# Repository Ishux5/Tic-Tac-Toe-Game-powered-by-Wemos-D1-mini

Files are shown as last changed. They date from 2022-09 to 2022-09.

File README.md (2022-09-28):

# Tic-Tac-Toe-Game-powered-by-Wemos-D1-mini

## Idea:

The Idea started when I was working on a birthday present for a friend. It was a 7 Segment Clock powered by an ESP32. The core part was to build something powered by a microcontroller by using a PCB and a Bettery Pack. I then setteled on building a Tic-Tac-Toe because I thought it was relatively simple. The code would be simple, the PCB-layout would be simple and it would be easy to manufacture a couple of them.

## Journey

After setteling on the idea I started working on the form. It shouldn't be to big and I wanted it to have a maximum size of 10 cm x 10 cm. After finishing the first 3D Model in Autodesk Fusion 360 I continued with creating the circuit which I never done before. I screen recorded my work and decided to create a little Video about how I made the PCB, Code and the casing. PCB and Code are older Versions and non functional!
Tic-Tac-Toe making of (https://youtu.be/2Q2LxaJ6QfE "Tic-Tac-Toe making of")
<br>
The first ordered sample worked but had a huge flaw as I connected the LEDs to the wrong Pins on the micro Controller. Pin 8 and 1 weren't functioning as internal Pullup pins. The second and current version is still flawed because of to small holes for the Power Switch. I have not reordered any PCBs with the right hole sizes.

## Finished Product

After all I am very Happy how it turned out. It is functioning as I wanted it, looks decend and the learning experience on the journey to the finished product was fun too. It has become more elaborate and costly than expected

## Parts

| Item # | Component | Quantity |
| :----- | :--- | :--- |
| 1 | [Cherry MX Blue switches, MX1A-E1NA][switchlink] | 9 |
| 2 | [AZDelivery Battery Shield for D1 Mini][shieldlink] | 1 |
| 3 | [AZDelivery D1 Mini NodeMcu ESP8266-12F][microcontrollerlink] | 1 |
| 4 | [LiPo 1200mAh 3,7V Batterie][lipolink] | 1 |
| 5 | [SK6812 MINI-E RGB][ledlink] | 11 |
| 6 | [SALECOM SS 13ASP][powerswtichlink] | 1 |
| 7 | [Short-Stroke switch 5mm][shortstrokelink] | 1 |
| 8 | [Micro USB to DIP breakout Board][usbbreakoutlink] | 1 |
| 9 | JST – Connecter Female 90° | 1 |
| 10 | [JST – Connector wire][jstwirelink] | 1 |
| 11 | 10k Ohm Resistor | 1 |
| 12 | 100k Ohm Resistor | 1 |
| 13 | [Micro USB Power Cable 20 cm][usbwirelink] | 1 |
| 14 | [M4 Threaded Inserts][insertslink] | 4 |
| 15 | M4 Cylindrical Screws | 4 |
| 16 | [Tic-Tac-Toe PCB][pcblink] | 1 |

[switchlink]: https://de.aliexpress.com/item/1005003772714638.html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
[shieldlink]: https://www.amazon.de/-/en/dp/B07XB75NTD/ref=twister_B07ZRK81LT?_encoding=UTF8&psc=1
[microcontrollerlink]: https://www.az-delivery.de/collections/alle-produkte/products/d1-mini
[lipolink]: https://www.ebay.de/itm/282581166241
[ledlink]: https://de.aliexpress.com/item/1005002865070175.html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
[powerswitchlink]: https://www.reichelt.de/schiebeschalter-1x-um-stehend-print-rm-4-7-ss-13asp-p112182.html?&nbc=1
[shortstrokelink]: https://www.reichelt.de/kurzhubtaster-6x6mm-hoehe-7-0mm-12v-vertikal-taster-9303-p44583.html?&nbc=1
[usbbreakoutlink]: https://www.amazon.de/gp/product/B07W13X3TD/ref=ppx_yo_dt_b_asin_title_o00_s00?ie=UTF8&psc=1
[jstwirelink]: https://www.reichelt.de/jst-stiftleiste-90-1x2-polig-ph-jst-ph2p-st90-p185056.html?&nbc=1
[usbwirelink]: https://www.reichelt.de/micro-usb-b-stecker-auf-freie-enden-sw-20-cm-usb-b-awg22-20-p292508.html?&nbc=1
[insertslink]: https://www.amazon.de/gp/product/B09CL4M6JB/ref=ppx_yo_dt_b_asin_title_o01_s02?ie=UTF8&psc=1
[pcblink]: https://www.pcbway.com/project/shareproject/Tic_Tac_Toe_5d14ccaf.html

## Assembly

1. Solder LEDs to the PCB (ground marked with while dot)
2. Solder Button 2 (opposite to D1 mini at LED2) to the PCB
3. Install the Software on the D1 mini
4. Solder D1 mini to the PCB
5. Solder the Power Switch, Resistors, JST – Connector and short-stroke switch to the PCB
6. Solder JST – Connector wire to the Battery shield
7. Solder Micro USB cable to the Micro USB breakout board
8. Insert the Button on the PCB through the larger hole in the 3D – Printed top part of the Casing
9. Insert rest of the Buttons in the Holes of the 3D – Printed top part of the Casing
10. Solder Buttons to the PCB
11. Connect the Battey and Micro USB Cable to the Battery Shield
12. Install M4 Threaded Inserts
13. Route Cables in the 3D – Printed bottom part of the Casing
14. Connect the JST – Male header with the JST – Female header on the PCB

## License

Shield: [][cc-by-nc-sa]

This work is licensed under a
[Creative Commons Attribution-NonCommercial-ShareAlike 4.0 International License][cc-by-nc-sa].

[][cc-by-nc-sa]

[cc-by-nc-sa]: http://creativecommons.org/licenses/by-nc-sa/4.0/
[cc-by-nc-sa-image]: https://licensebuttons.net/l/by-nc-sa/4.0/88x31.png
[cc-by-nc-sa-shield]: https://img.shields.io/badge/License-CC%20BY--NC--SA%204.0-lightgrey.svg

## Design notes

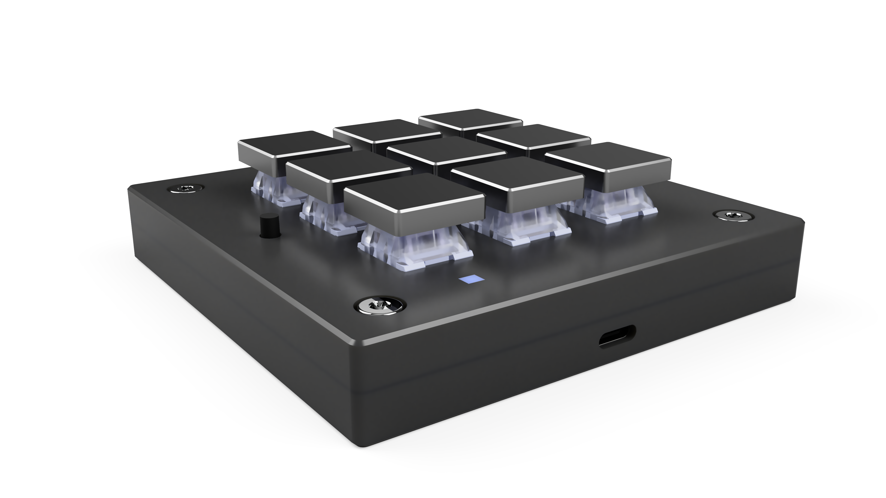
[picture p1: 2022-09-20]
Images/Konstruktion_2022-Sep-20_01-05-23AM-000_CustomizedView2792266026_png.png

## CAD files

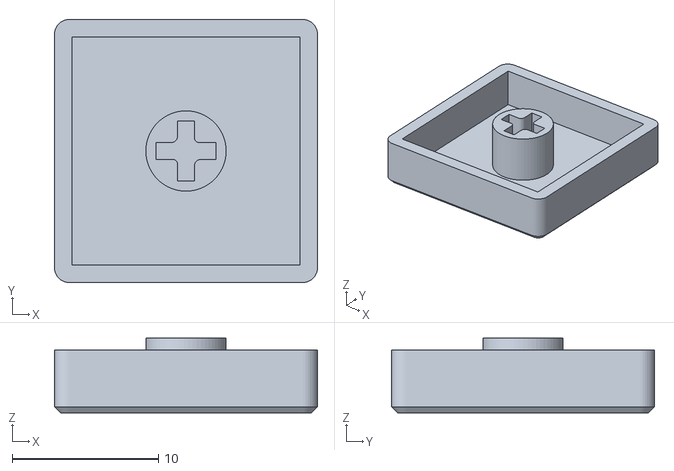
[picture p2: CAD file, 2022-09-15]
Pre1 Keycap.stl
18.0 x 18.0 x 5.10

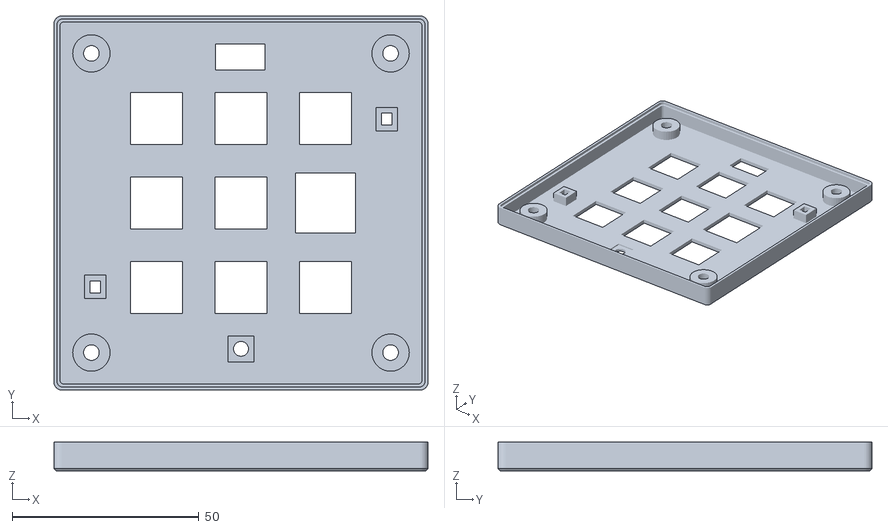
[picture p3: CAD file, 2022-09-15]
Pre2 Deckel.stl
100.0 x 100.0 x 7.70

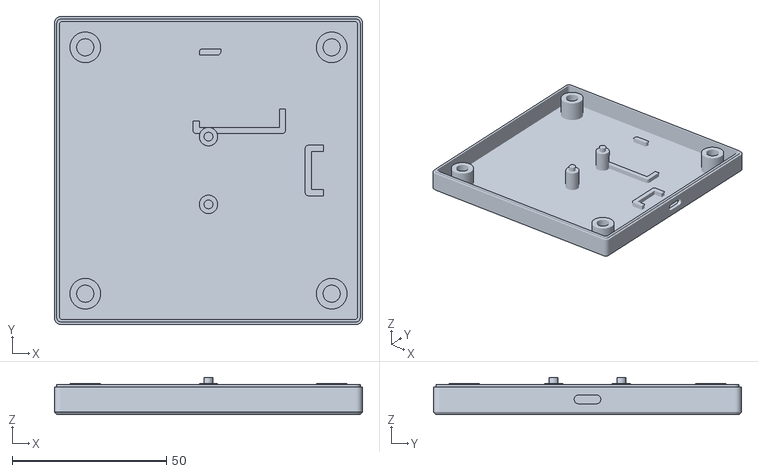
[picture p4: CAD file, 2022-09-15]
Pre2 Boden.stl
100.0 x 100.0 x 12.1

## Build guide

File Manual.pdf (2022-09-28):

# Arduino Based Tic-Tac-Toe

By Christian Rahn

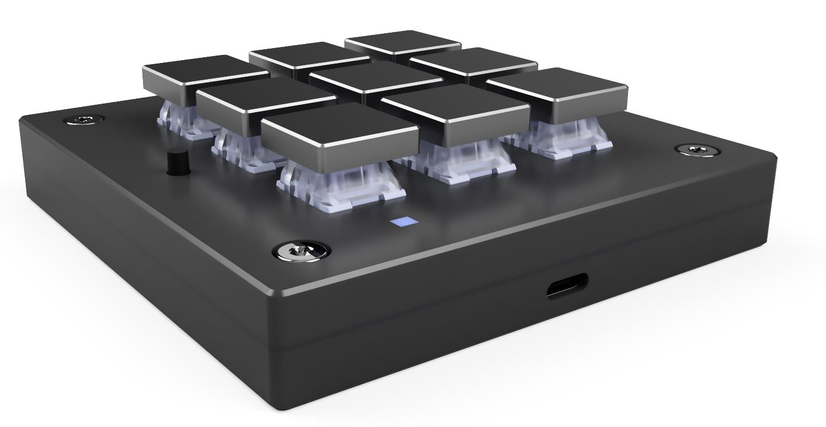
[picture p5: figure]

## Content

## License

This work is licensed under a Creative Commons Attribution-NonCommercial-ShareAlike 4.0 International License. (http://creativecommons.org/licenses/by-nc-sa/4.0/)

## Prolog

### Idea:

The Idea started when I was working on a birthday present for a friend. It was a 7 Segment Clock powered by an ESP32. The core part was to build something powered by a microcontroller by using a PCB and a Battery Pack. I then settled on building a Tic-Tac-Toe because I thought it was relatively simple. The code would be simple, the PCB-layout would be simple, and it would be easy to manufacture a couple of them.

### Journey:

After settling on the idea, I started working on the form. It shouldn't be too big, and I wanted it to have a maximum size of 10 cm x 10 cm. After finishing the first 3D Model in Autodesk Fusion 360 I continued with creating the circuit which I never done before. I screen recorded my work and decided to create a little Video about how I made the PCB, Code and the casing. PCB and Code are older Versions and nonfunctional! https://youtu.be/2Q2LxaJ6QfE The first ordered sample worked but had a huge flaw as the LEDs were connected to the wrong Pins on the micro-Controller. Pins 8 and 1 weren't functioning as internal Pullup pins. The second and current version is still flawed because of too small holes for the Power Switch. I have not reordered any PCBs with the right hole sizes.

### Finished Product:

After all I am very Happy how it turned out. It is functioning as I wanted it, looks descend and the learning experience on the journey to the finished product was fun too. It has become more elaborate and costly than expected

## Materials

The following Materials were used:
Item #: | Component: | Quantity:
1 | Cherry MX Blue switches, MX1A-E1NA (https://de.aliexpress.com/item/1005003772714638.html) | 9
2 | AZDelivery Battery Shield for D1 Mini (https://www.amazon.de/-/en/dp/B07XB75NTD/ref=twister_B07ZRK81LT?_encoding=UTF8&psc=1) | 1
3 | AZDelivery D1 Mini NodeMcu ESP8266-12F | 1
4 | LiPo 1200mAh 3,7V Batterie (https://www.ebay.de/itm/282581166241) | 1
5 | SK6812 MINI-E RGB (https://de.aliexpress.com/item/1005002865070175.html) | 11
6 | SALECOM SS 13ASP (https://www.reichelt.de/schiebeschalter-1x-um-stehend-print-rm-4-7-ss-13asp-p112182.html?&nbc=1) | 1
7 | Short-Stroke switch 5mm (https://www.reichelt.de/kurzhubtaster-6x6mm-hoehe-7-0mm-12v-vertikal-taster-9303-p44583.html?&nbc=1) | 1
8 | Micro USB to DIP breakout Board (https://www.amazon.de/gp/product/B07W13X3TD/ref=ppx_yo_dt_b_asin_title_o00_s00?ie=UTF8&psc=1) | 1
9 | JST – Connecter Female 90° | 1
10 | JST – Connector wire (https://www.reichelt.de/jst-stiftleiste-90-1x2-polig-ph-jst-ph2p-st90-p185056.html?&nbc=1) | 1
11 | 10k Ohm Resistor | 1
12 | 100k Ohm Resistor | 1
13 | Micro USB Power Cable 20 cm (https://www.reichelt.de/micro-usb-b-stecker-auf-freie-enden-sw-20-cm-usb-b-awg22-20-p292508.html?nbc=1) | 1
14 | M4 Threaded Inserts (https://www.amazon.de/gp/product/B09CL4M6JB/ref=ppx_yo_dt_b_asin_title_o01_s02?ie=UTF8&psc=1) | 4
15 | M4 Cylindrical Screws | 4
16 | Tic-Tac-Toe PCB (https://www.pcbway.com/project/shareproject/Tic_Tac_Toe_5d14ccaf.html) | 1

## Assembly

1. Solder LEDs to the PCB (ground marked with while dot)
2. Solder Button 2 (opposite to D1 mini at LED2) to the PCB
3. Install the Software on the D1 mini
4. Solder D1 mini to the PCB
5. Solder the Power Switch, Resistors, JST – Connector and short-stroke switch to the PCB
6. Solder JST – Connector wire to the Battery shield
7. Solder Micro USB cable to the Micro USB breakout board
8. Insert the Button on the PCB through the larger hole in the 3D – Printed top part of the Casing
9. Insert rest of the Buttons in the Holes of the 3D – Printed top part of the Casing
10. Solder Buttons to the PCB
11. Connect the Battey and Micro USB Cable to the Battery Shield
12. Install M4 Threaded Inserts
13. Route Cables in the 3D – Printed bottom part of the Casing
14. Connect the JST – Male header with the JST – Female header on the PCB

## Charging

Charging via micro-USB 5V 500mA. While the battery is charging a red LED is on. If the charging is complete a green LED will light up. The LEDs can be seen through Button 9 if the Battery Shield is installed correctly.

## Software

The Software and other Project relevant information is available on my Github. (https://github.com/Ishux5)

## Colors

The LED-Colors can be changed by entering HSV-Values in the “Colors”-Section as desired. Example Colors:
Color: | HSV:
Red | (0, 255, 255)
Orange | (19, 255, 255)
Yellow | (44, 255, 255)
Light Green | (87, 255, 255)
Light Blue | (145, 255, 255)
Dark Blue | (170, 255, 255)
Purple | (185, 255, 255)
Pink | (226, 255, 255)

## Links

Github: https://github.com/Ishux5/Tic-Tac-Toe-powered-by-D1-mini
PCB: https://www.pcbway.com/project/shareproject/Tic_Tac_Toe_5d14ccaf.html

Abb. 1: Pin Layout SK6812 MINI-E RGB

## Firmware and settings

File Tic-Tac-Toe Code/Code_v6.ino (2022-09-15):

// by Christian Rahn


#include <FastLED.h>

// LEDs
#define LED_PIN D0
#define LED_NUM 11
#define COLOR_ORDER GRB
#define LED_TYPE WS2812
#define LED_BRIGHTNESS 100

CRGB LED[LED_NUM];

// Colors
#define P1COLOR CHSV(172, 225, 255)    // Blue
#define P2COLOR CHSV(86, 255, 255)     // Green
#define DRAWCOLOR CHSV(0, 0, 255)      // White
#define WRONGCOLOR CHSV(255, 255, 255) // Red
#define LEDOFF CHSV(0, 0, 0)           // OFF

// Buttons
#define BUTTON1_PIN D5
#define BUTTON2_PIN D6
#define BUTTON3_PIN 1
#define BUTTON4_PIN D7
#define BUTTON5_PIN 3
#define BUTTON6_PIN D1
#define BUTTON7_PIN D2
#define BUTTON8_PIN D3
#define BUTTON9_PIN D4
#define BUTTONRST_PIN A0

int playerReset[3][3]{
    {10, 20, 30},
    {40, 50, 60},
    {70, 80, 90}};

int player1Field[3][3]{
    {10, 20, 30},
    {40, 50, 60},
    {70, 80, 90}};

int player2Field[3][3]{
    {10, 20, 30},
    {40, 50, 60},
    {70, 80, 90}};

bool gameWon = false;
byte activePlayer = 2;
byte playerMoves = 0;
bool switchingStatus = false;

void setup()
{
    activePlayer = randomizeBeginner();
    FastLED.setBrightness(LED_BRIGHTNESS);
    showPlayerLED(activePlayer);

    FastLED.addLeds<LED_TYPE, LED_PIN, COLOR_ORDER>(LED, LED_NUM);
    pinMode(BUTTON1_PIN, INPUT_PULLUP);
    pinMode(BUTTON2_PIN, INPUT_PULLUP);
    pinMode(BUTTON3_PIN, INPUT_PULLUP);
    pinMode(BUTTON4_PIN, INPUT_PULLUP);
    pinMode(BUTTON5_PIN, INPUT_PULLUP);
    pinMode(BUTTON6_PIN, INPUT_PULLUP);
    pinMode(BUTTON7_PIN, INPUT_PULLUP);
    pinMode(BUTTON8_PIN, INPUT_PULLUP);
    pinMode(BUTTON9_PIN, INPUT_PULLUP);
}

void loop()
{

    switchingStatus = buttonPress(player1Field, player2Field, activePlayer);
    showLEDs(player1Field, player2Field, activePlayer, true);

    if (gameWon == false)
    {
        if (activePlayer == 1)
        {
            gameWon = checkWin(player1Field, playerMoves);
        }
        else if (activePlayer == 2)
        {
            gameWon = checkWin(player2Field, playerMoves);
        }
    }
    else
    {
        if (playerMoves == 9)
        {
            for (int x = 0; x < 9; x++)
            {
                LED[x] = DRAWCOLOR;
            }
            FastLED.show();
            resetGame(playerReset);
        }
        else
        {
            showWin(activePlayer, player1Field, player2Field, playerReset);
            resetGame(playerReset);
        }
    }

    if (switchingStatus == true && gameWon == false)
    {
        activePlayer = switchPlayer(activePlayer);
        Serial.println(switchingStatus);
        switchingStatus = false;
    }
    Serial.println(switchingStatus);
    Serial.println("");
}

void showLEDs(int player1Field[3][3], int player2Field[3][3], int activePlayer, bool includePlayerLEDs)

{
    int playerField[3][3]{
        {0, 0, 0},
        {0, 0, 0},
        {0, 0, 0}};

    if (activePlayer == 1)
    {
        copyField(playerField, player1Field);
    }
    else if (activePlayer == 2)
    {
        copyField(playerField, player2Field);
    }

    for (int row = 0; row < 3; row++)
    {
        for (int col = 0; col < 3; col++)
        {
            int LEDnumber = calculateLED(row, col);
            if (playerField[row][col] == 1)
            {
                if (activePlayer == 1)
                {
                    LED[LEDnumber] = P1COLOR;
                }
                else if (activePlayer == 2)
                {
                    LED[LEDnumber] = P2COLOR;
                }
            }
        }
    }

    if (includePlayerLEDs == true)
    {
        showPlayerLED(activePlayer);
    }

    FastLED.show();
}

void copyField(int changedField[3][3], int initialField[3][3])
{
    for (int col = 0; col < 3; col++)
    {
        for (int row = 0; row < 3; row++)
        {
            changedField[row][col] = initialField[row][col];
        }
    }
}

int calculateLED(int LEDrow, int LEDcol)
{
    return LEDrow * 3 + LEDcol;
}

int switchPlayer(int activePlayer)
{
    playerMoves += 1;
    if (activePlayer == 1)
    {
        return 2;
    }
    else if (activePlayer == 2)
    {
        return 1;
    }
}

int buttonPress(int player1Field[3][3], int player2Field[3][3], int activePlayer)
{
    if (digitalRead(BUTTON1_PIN) == LOW)
    {
        while (digitalRead(BUTTON1_PIN) == LOW)
        {
            delay(20);
        }
        if (wrongField(player1Field, player2Field, 0, 0, activePlayer) == false)
        {
            updateField(player1Field, player2Field, activePlayer, 0, 0);
        }
        else
        {
            return false;
        }

        return true;
    }
    else if (digitalRead(BUTTON2_PIN) == LOW)
    {
        while (digitalRead(BUTTON2_PIN) == LOW)
        {
            delay(20);
        }
        if (wrongField(player1Field, player2Field, 0, 1, activePlayer) == false)
        {
            updateField(player1Field, player2Field, activePlayer, 0, 1);
        }
        else
        {
            return false;
        }
        return true;
    }
    else if (digitalRead(BUTTON3_PIN) == LOW)
    {
        while (digitalRead(BUTTON3_PIN) == LOW)
        {
            delay(20);
        }
        if (wrongField(player1Field, player2Field, 0, 2, activePlayer) == false)
        {
            updateField(player1Field, player2Field, activePlayer, 0, 2);
        }
        else
        {
            return false;
        }
        return true;
    }
    else if (digitalRead(BUTTON4_PIN) == LOW)
    {
        while (digitalRead(BUTTON4_PIN) == LOW)
        {
            delay(20);
        }
        if (wrongField(player1Field, player2Field, 1, 0, activePlayer) == false)
        {
            updateField(player1Field, player2Field, activePlayer, 1, 0);
        }
        else
        {
            return false;
        }
        return true;
    }
    else if (digitalRead(BUTTON5_PIN) == LOW)
    {
        while (digitalRead(BUTTON5_PIN) == LOW)
        {
            delay(20);
        }
        if (wrongField(player1Field, player2Field, 1, 1, activePlayer) == false)
        {
            updateField(player1Field, player2Field, activePlayer, 1, 1);
        }
        else
        {
            return false;
        }
        return true;
    }
    else if (digitalRead(BUTTON6_PIN) == LOW)
    {
        while (digitalRead(BUTTON6_PIN) == LOW)
        {
            delay(20);
        }
        if (wrongField(player1Field, player2Field, 1, 2, activePlayer) == false)
        {
            updateField(player1Field, player2Field, activePlayer, 1, 2);
        }
        else
        {
            return false;
        }
        return true;
    }
    else if (digitalRead(BUTTON7_PIN) == LOW)
    {
        while (digitalRead(BUTTON7_PIN) == LOW)
        {
            delay(20);
        }
        if (wrongField(player1Field, player2Field, 2, 0, activePlayer) == false)
        {
            updateField(player1Field, player2Field, activePlayer, 2, 0);
        }
        else
        {
            return false;
        }
        return true;
    }
    else if (digitalRead(BUTTON8_PIN) == LOW)
    {
        while (digitalRead(BUTTON8_PIN) == LOW)
        {
            delay(20);
        }
        if (wrongField(player1Field, player2Field, 2, 1, activePlayer) == false)
        {
            updateField(player1Field, player2Field, activePlayer, 2, 1);
        }
        else
        {
            return false;
        }
        return true;
    }
    else if (digitalRead(BUTTON9_PIN) == LOW)
    {
        while (digitalRead(BUTTON9_PIN) == LOW)
        {
            delay(20);
        }
        if (wrongField(player1Field, player2Field, 2, 2, activePlayer) == false)
        {
            updateField(player1Field, player2Field, activePlayer, 2, 2);
        }
        else
        {
            return false;
        }
        return true;
    }
    else
    {
        return false;
    }
}

void updateField(int player1Field[3][3], int player2Field[3][3], int activePlayer, int row, int col)
{
    if (activePlayer == 1)
    {
        player1Field[row][col] = 1;
    }
    else if (activePlayer == 2)
    {
        player2Field[row][col] = 1;
    }
}

bool checkWin(int playerField[3][3], int moves)
{
    for (int row = 0; row < 3; row++)
    {
        if (
            ((playerField[row][0] == playerField[row][1]) && (playerField[row][1] == playerField[row][2])) || ((playerField[0][row] == playerField[1][row]) && (playerField[1][row] == playerField[2][row])))
        {
            return true;
        }
    }
    if (
        ((playerField[0][0] == playerField[1][1]) && (playerField[1][1] == playerField[2][2])) ||
        ((playerField[2][0] == playerField[1][1]) && (playerField[1][1] == playerField[0][2])))
    {
        return true;
    }
    else if (moves == 9)
    {
        return true;
    }
    else
    {
        return false;
    }
}

void showWin(int playerWon, int player1Field[3][3], int player2Field[3][3], int resetField[3][3])
{
    if (playerWon == 1)
    {
        copyField(player2Field, resetField);
        showWinLEDs(player1Field, playerWon);
    }
    else if (playerWon == 2)
    {
        copyField(player1Field, resetField);
        showWinLEDs(player2Field, playerWon);
    }
}

void showWinLEDs(int playerWonField[3][3], int playerWon)
{
    for (int x = 0; x < 9; x++)
    {
        LED[x] = LEDOFF;
    }

    for (int row = 0; row < 3; row++)
    {
        for (int col = 0; col < 3; col++)
        {
            int LEDnumber = calculateLED(row, col);

            if (playerWonField[row][col] == 1)
            {
                if (playerWon == 1)
                {
                    LED[LEDnumber] = P1COLOR;
                }
                else if (playerWon == 2)
                {
                    LED[LEDnumber] = P2COLOR;
                }
            }
        }
    }
    FastLED.show();
}

void resetGame(int resetField[3][3])
{
    while (gameWon == true)
    {
        if (analogRead(BUTTONRST_PIN) == 1024)
        {
            copyField(player1Field, resetField);
            copyField(player2Field, resetField);

            for (int x = 0; x < 9; x++)
            {
                LED[x] = LEDOFF;
            }

            playerMoves = 0;
            activePlayer = randomizeBeginner();
            showPlayerLED(activePlayer);
            FastLED.show();
            gameWon = false;
        }
        else
        {
            delay(1);
        }
    }
}

int randomizeBeginner()
{
    byte randomNumber = 0;
    randomNumber = random(1, 3);
    return randomNumber;
}

void showPlayerLED(int activePlayer)
{
    if (activePlayer == 1)
    {
        LED[9] = P1COLOR;
        LED[10] = LEDOFF;
    }
    else if (activePlayer == 2)
    {
        LED[9] = LEDOFF;
        LED[10] = P2COLOR;
    }
}

bool wrongField(int player1Field[3][3], int player2Field[3][3], int row, int col, int activePlayer)
{
    if (player1Field[row][col] == 1 || player2Field[row][col] == 1)
    {
        LED[calculateLED(row, col)] = WRONGCOLOR;
        FastLED.show();
        delay(400);
        showLEDs(player1Field, player2Field, 1, false);
        showLEDs(player1Field, player2Field, 2, false);
        return true;
    }
    else
    {
        return false;
    }
}
